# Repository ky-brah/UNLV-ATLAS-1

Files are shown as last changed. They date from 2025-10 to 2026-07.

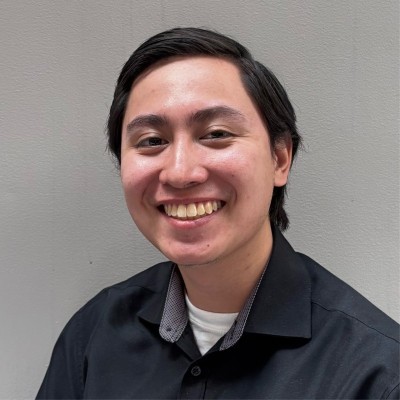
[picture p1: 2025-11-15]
img/Leo.jpg

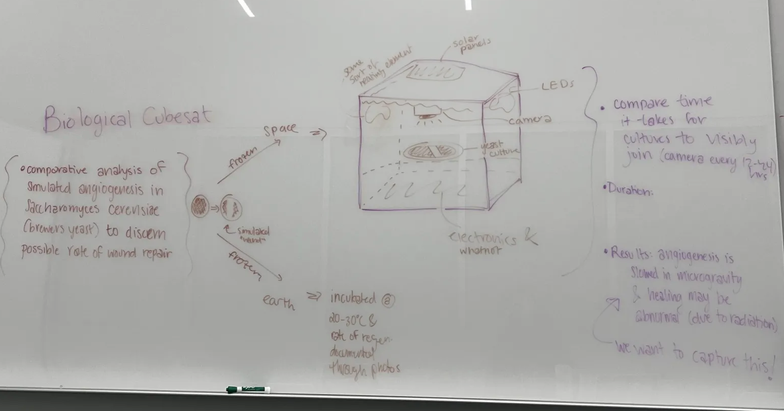
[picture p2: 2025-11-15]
img/biocubeidea.png

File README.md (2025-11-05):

# UNLV-ATLAS-1

UNLV ATLAS-1 is an independent research project at the University of Nevada, Las Vegas, dedicated to making high-altitude ballooning tests and CubeSat development more accessible and attainable within the Nevada region.

This GitHub repository documents our ongoing progress toward our mission: to design, build, and launch a CubeSat from the state of Nevada. Our goal is not only to showcase innovation but also to strengthen Nevada’s presence in the aerospace industry. We are currently developing ATLAS-1, an open-source mock satellite (“mocksat”) that enables high-altitude balloon launches on a budget. All source files and resources for this project can be found here.

We would like to acknowledge jhammerberg’s qbSat-v2, whose original mocksat design served as the foundation upon which ATLAS-1 was developed and improved.

We encourage others to explore our design—modify it, build upon it, and make it their own.

Through this project, we aim to inspire future engineers and establish Nevada as a recognized contributor to the global space community.

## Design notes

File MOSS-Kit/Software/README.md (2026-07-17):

# MOSS Kit

A hands-on kit for building, flying, and recovering a real telemetry payload — the hardware, the code, and the docs that tie them together. Built by students, for students, as part of UNLV's ATLAS-1 high-altitude balloon platform.

## What's here

The folders in this directory are already arranged in the exact structure each Raspberry Pi expects. Don't rearrange them — the scripts write files relative to their own location, and the ground station's nginx setup depends on this layout.

-  Flight Pi (payload). The main flight program, shared pipeline modules, LoRa radio driver, and preflight tests. A `runs/` folder gets created at runtime, one timestamped folder per launch.
- ground — Ground Pi. The receiver, the dashboard it serves, the shared modules, and optional test scripts for checking things work with no radio attached.
- `MOSS-docs.html` — Full setup documentation. Open it in any browser.

## Getting the files onto your Pis

Download the whole thing as a ZIP straight from GitHub rather than cloning or copying files one at a time:

You can either get the whole repository, or simply the software folder.

The ZIP preserves the folder structure exactly as it appears here, which is why this is the recommended way to get started.

## The most important rule

`tm_schema.py` and `protocol_tm.py` must be **byte-identical copies** on both Pis. They aren't shared over the network — each Pi keeps its own copy. If the two drift apart, the ground station can't decode anything the flight Pi sends.

Because the ZIP gives both Pis the same starting copies, downloading fresh is the simplest way to guarantee they match. To verify later:

```bash
sha256sum ~/hab/tm_schema.py ~/hab/protocol_tm.py       # flight Pi
sha256sum ~/ground/tm_schema.py ~/ground/protocol_tm.py # ground Pi
```
Note: The above file paths /hab may not be accurate to yours

If the fingerprints match, the files are the same.

## Step-by-step guide

**Open `MOSS-docs.html` in a browser** for the full walkthrough. It covers everything below in detail, with commands you can copy.

The recommended order:

1. **Main setup** — do this on both Pis. OS, connection, interfaces, Python. Four steps, once per Pi. Nothing else works until this is done.
2. **Ground station** — build and test this first. Install nginx, set the folder path, then prove the dashboard works using fake data. No radio needed, nothing to wire.
3. **Flight Pi** — the payload. Wire the sensors, confirm the bus sees each one, install the drivers, then run it. With the ground station already working, you can watch real telemetry arrive immediately.
4. **Field hotspot** — last of all. Only once both Pis work on ordinary Wi-Fi. This is purely for the launch site, where no network exists.

Ground before flight is deliberate: the ground station can be fully tested on a desk, so when you power up the payload, anything that goes wrong is on the flight side rather than a mystery split between the two.

## Hardware

| Component | Role |

| Raspberry Pi 3B+ | Flight computer |
| Sensor suite (BME280, LTR390, TSL2591, ICM20948) | Environmental + motion data |
| Raspberry Pi Camera v2 | Imaging |

## Notes

- Paths in the docs use `unlvcube1` as the username (`/home/unlvcube1/hab/`). Yours will read `/home/<your-username>/` with whatever name you chose in Raspberry Pi Imager.
- Folder names (`hab`, `ground`) are examples. The structure is what matters.
- Wi-Fi never reaches the balloon in flight. It's only for the ground: starting scripts before launch and pulling data after recovery.

Questions, bugs, or ideas? Reach us at *contact TBD*.

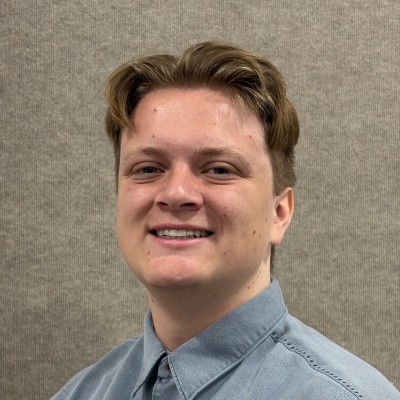
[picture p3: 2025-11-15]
img/Christian.jpg

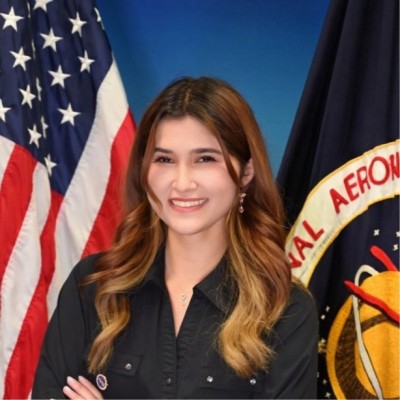
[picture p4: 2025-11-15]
img/Kylee.jpg

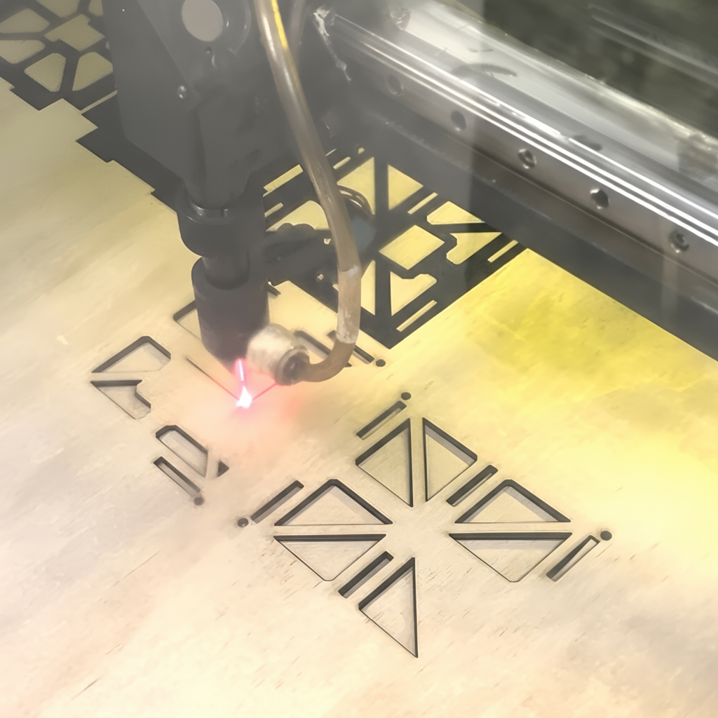
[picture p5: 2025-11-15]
img/Laser.jpg

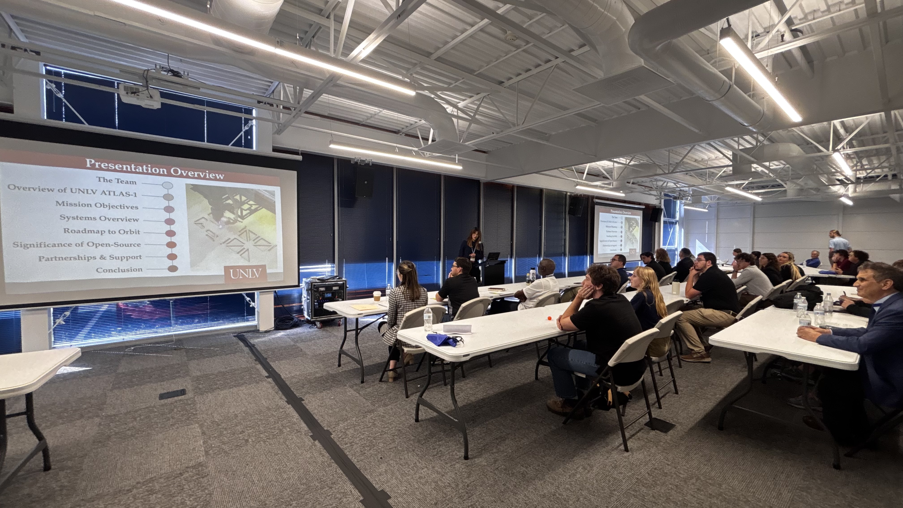
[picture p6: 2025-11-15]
img/present.jpeg

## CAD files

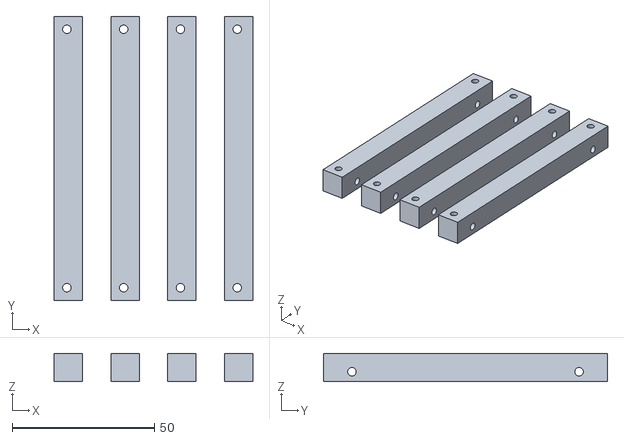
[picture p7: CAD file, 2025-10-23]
OutDated/ATLAS PILLAR V2.stl
70.0 x 100.0 x 10.0

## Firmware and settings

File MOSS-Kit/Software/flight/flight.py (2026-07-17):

#!/usr/bin/env python3
"""
flight.py
flight-side telemetry script.

Main idea
---------
- Build a telemetry record every 2 seconds (0.5 Hz).
- Log every record locally as JSONL (safety net — survives even if every
  radio packet is lost).
- Pack the record into a 22-byte binary payload via tm_schema.pack().
- Wrap that payload in a TM frame via protocol_tm.build_frame().
- Transmit the frame twice back-to-back (2x retransmit strategy).
- Run the camera in its own worker thread so subprocess capture never
  blocks the main telemetry loop.

"""

# =====================================================================
# STUDENT ORIENTATION — read this first
# ---------------------------------------------------------------------
# This program runs ON THE PAYLOAD (the Raspberry Pi that flies). Its job
# is a loop: read every sensor, write the full reading to the SD card,
# then send a compact copy to the ground over the radio. Repeat every 2s.
#
# Two rules the code follows everywhere:
#   1. NEVER let one broken part crash the flight. Every sensor/radio read
#      is wrapped so a failure is caught, recorded in the record's "errors",
#      and the loop keeps going. A dead sensor must not silence the others.
#   2. The SD card log (JSONL) is the source of truth. The radio is
#      best-effort — many packets are lost in flight — so the local log is
#      what you actually analyze afterward.
#
# The "(value, error)" return pattern you'll see everywhere is how rule #1
# works: a function hands back BOTH a result AND an error string (one is
# always None), so the caller can log the problem instead of crashing.
# =====================================================================

# -------------------------
# Standard libraries
# -------------------------
import json
import math
import queue
import shutil
import subprocess
import threading
import time
from datetime import datetime, timezone
from pathlib import Path
from typing import Any, Dict, Optional

# -------------------------
# Hardware / sensor libraries
# -------------------------
# These only exist on the Raspberry Pi. board/busio (Adafruit Blinka) expose
# the Pi's I2C pins; the rest are drivers, one per sensor chip on the I2C bus:
#   BME280  -> temperature, pressure, humidity
#   LTR390  -> UV + ambient light
#   TSL2591 -> lux / infrared / visible light
#   ICM20948 (IMU) -> acceleration + rotation (gyro)
import board
import busio
from adafruit_bme280 import basic as adafruit_bme280
import adafruit_ltr390
import adafruit_tsl2591
from adafruit_icm20x import ICM20948

# UPS power monitoring (Waveshare UPS HAT E)
from smbus2 import SMBus

# LoRa driver
import sx126x

# Shared telemetry protocol (MUST match ground exactly)
from protocol_tm import build_frame as tm_build_frame

# Binary wire-format schema (MUST match ground exactly)
import tm_schema


# ===========================================================
# Constants
# ===========================================================

# ---- Telemetry pacing ----
TELEMETRY_HZ = 0.5           # 1 packet every 2 seconds
LOOP_PERIOD_S = 1.0 / TELEMETRY_HZ

# ---- UPS (Waveshare UPS HAT E) ----
UPS_I2C_ADDR   = 0x2D
LOW_BATT_PCT   = 20
CRIT_BATT_PCT  = 10
LOW_BATT_V     = 3.55

# ---- BME280 ----
# BME280 lives on either 0x76 or 0x77; we try 0x76 first.
BME280_PRIMARY_ADDR   = 0x76
BME280_FALLBACK_ADDR  = 0x77

# ---- IMU (ICM20948) ----
# Inertial Measurement Unit: accelerometer + gyroscope, on I2C address 0x68.
IMU_I2C_ADDR = 0x68

# Sea-level pressure used as fallback altitude reference if we can't
# capture a launch-pad reading at startup (in hPa).
DEFAULT_REF_PRESSURE_HPA = 1013.25

# ---- Camera ----
IMAGE_PERIOD_S       = 25 # capture cadence
IMG_W, IMG_H         = 3280, 2464
IMG_Q                = 85
CAMERA_TIMEOUT_S     = 8
CRIT_IMAGE_PERIOD_S  = 60 # slow capture when battery critical

# ---- LoRa ----
LORA_PORT          = "/dev/serial0"
LORA_FREQ_MHZ      = 915
LORA_SRC_ADDR      = 1
LORA_DEST_ADDR     = 65535
LORA_POWER_DBM     = 22
LORA_AIR_SPEED     = 2400
LORA_NET_ID        = 0
LORA_CRYPT         = 0
LORA_RSSI          = True
LORA_BUFFER_SIZE   = 240
LORA_BASE_FREQ_MHZ = 850 # 900MHz modules: offset = freq_mhz - 850

# 2x retransmit — send each frame twice back-to-back for resilience.
TX_COPIES          = 2
TX_GAP_S           = 0.05  # tiny gap between copies so UART isn't slammed

# ---- Storage ----
MAX_LOG_MB   = 200
MAX_IMAGE_MB = 500


# ==================================================================
# Time helpers
# ===================================================================
def utc_timestamp_iso() -> str:
    return datetime.now(timezone.utc).isoformat(timespec="milliseconds")


def sleep_to_rate(loop_start_s: float, period_s: float) -> None:
    """Sleep just long enough to keep the main loop at the target rate."""
    elapsed = time.time() - loop_start_s
    time.sleep(max(0.0, period_s - elapsed))


# ==================================================================
# Local logging (JSONL)
# ===================================================================
def append_jsonl(path: Path, record: Dict[str, Any]) -> Optional[str]:
    # JSONL = one complete JSON object per line. Appending a line at a time
    # means a power loss only risks the last line, not the whole file.
    # Returns None on success or an error string (never raises — keep flying).
    try:
        with path.open("a", encoding="utf-8") as f:
            f.write(json.dumps(record, separators=(",", ":"), ensure_ascii=False) + "\n")
        return None
    except Exception as e:
        return repr(e)


# ====================================================================
# Storage cleanup (delete oldest files when folder over the cap)
# =====================================================================
def cleanup_folder_to_mb(folder: Path, max_mb: int) -> int:
    if not folder.exists():
        return 0

    max_bytes = max_mb * 1024 * 1024
    files = [p for p in folder.rglob("*") if p.is_file()]
    files.sort(key=lambda p: p.stat().st_mtime)

    total = sum(p.stat().st_size for p in files)
    if total <= max_bytes:
        return 0

    deleted = 0
    for p in files:
        try:
            size = p.stat().st_size
            p.unlink()
            total -= size
            deleted += 1
            if total <= max_bytes:
                break
        except Exception:
            pass
    return deleted


# ======================================================================
# UPS helpers
# ======================================================================
def ups_read_u16(bus: SMBus, reg: int) -> int:
    # The battery gauge stores values across two 8-bit registers. Read the low
    # byte and high byte, then stitch them into one unsigned 16-bit number.
    lo = bus.read_byte_data(UPS_I2C_ADDR, reg)
    hi = bus.read_byte_data(UPS_I2C_ADDR, reg + 1)
    return (hi << 8) | lo


def ups_read_i16(bus: SMBus, reg: int) -> int:
    # Same as above but SIGNED: current is negative when discharging, so a
    # value with the top bit set is converted to its negative (two's-complement).
    v = ups_read_u16(bus, reg)
    return v - 65536 if v & 0x8000 else v


def read_ups_status(bus: SMBus) -> tuple[Dict[str, Any], Optional[str]]:
    try:
        batt_mv  = ups_read_u16(bus, 0x20)
        batt_ma  = ups_read_i16(bus, 0x22)
        batt_pct = ups_read_u16(bus, 0x24)
        rem_mah  = ups_read_u16(bus, 0x26)
        rem_min  = ups_read_u16(bus, 0x28)
        return {
            "battery_v": batt_mv / 1000.0,
            "battery_a": batt_ma / 1000.0,
            "battery_pct": batt_pct,
            "remaining_mah": rem_mah,
            "remaining_min": rem_min,
        }, None
    except Exception as e:
        return {}, repr(e)


def compute_battery_alerts(power: Dict[str, Any]) -> list[str]:
    alerts: list[str] = []
    pct = power.get("battery_pct")
    v   = power.get("battery_v")

    if isinstance(pct, (int, float)):
        if pct <= CRIT_BATT_PCT:
            alerts.append("BATT_CRIT_PCT")
        elif pct <= LOW_BATT_PCT:
            alerts.append("BATT_LOW_PCT")

    if isinstance(v, (int, float)) and v <= LOW_BATT_V:
        alerts.append("BATT_LOW_V")

    return alerts


# =======================================================================
# Pi health helpers (kept for JSONL log; not in radio packet)
# ========================================================================
def _run(cmd: list[str]) -> tuple[str, Optional[str]]:
    try:
        out = subprocess.check_output(cmd, stderr=subprocess.STDOUT, text=True)
        return out.strip(), None
    except Exception as e:
        return "", repr(e)


def read_cpu_temp_c() -> tuple[Optional[float], Optional[str]]:
    out, err = _run(["vcgencmd", "measure_temp"])
    if err:
        return None, err
    try:
        return float(out.split("=")[1].split("'")[0]), None
    except Exception as e:
        return None, repr(e)


def read_disk_free_mb(path: Path) -> tuple[Optional[float], Optional[str]]:
    try:
        return shutil.disk_usage(str(path)).free / (1024 * 1024), None
    except Exception as e:
        return None, repr(e)


def read_pi_health(data_root: Path) -> tuple[Dict[str, Any], Dict[str, str]]:
    health: Dict[str, Any] = {}
    errors: Dict[str, str] = {}

    cpu_temp, err = read_cpu_temp_c()
    if err:
        errors["cpu_temp"] = err
    else:
        health["cpu_temp_c"] = cpu_temp

    disk_free, err = read_disk_free_mb(data_root)
    if err:
        errors["disk_free"] = err
    else:
        health["disk_free_mb"] = disk_free

    return health, errors


# ======================================================================
# Sensors (BME280 + LTR390 + TSL2591 + ICM20948)
# =======================================================================
def init_i2c_bus() -> busio.I2C:
    return busio.I2C(board.SCL, board.SDA)


def init_sensors(i2c: busio.I2C) -> Dict[str, Any]:
    """
    Initialize all I2C sensors. Each init is independent: one sensor failing
    does not stop the others. Init failures are recorded in
    sensors["_init_errors"] so downstream telemetry can surface the real
    reason a field shows up null.

    BME280 address is commonly 0x76 or 0x77. We try 0x76 first, then 0x77.
    """
    # Each sensor gets its own slot, defaulting to None. If a sensor fails to
    # initialize, its slot stays None and the rest still work — later reads
    # check "is this None?" before using it. Init errors collect in one dict.
    sensors: Dict[str, Any] = {
        "bme280_sensor": None,
        "ltr390_sensor": None,
        "tsl2591_sensor": None,
        "imu_sensor": None,
        "_init_errors": {},
    }
    init_errors: Dict[str, str] = {}

    # Each try/except below is independent on purpose: a missing or broken
    # sensor records its error and the next sensor still gets initialized.

    # --- BME280 (temp/pressure/humidity) ---
    # Try address 0x76 first, fall back to 0x77 (depends on the breakout).
    try:
        sensors["bme280_sensor"] = adafruit_bme280.Adafruit_BME280_I2C(
            i2c, address=BME280_PRIMARY_ADDR
        )
    except Exception as e76:
        try:
            sensors["bme280_sensor"] = adafruit_bme280.Adafruit_BME280_I2C(
                i2c, address=BME280_FALLBACK_ADDR
            )
        except Exception as e77:
            init_errors["bme280_init"] = (
                f"0x76 failed: {type(e76).__name__}: {e76}; "
                f"0x77 failed: {type(e77).__name__}: {e77}"
            )

    # --- LTR390 (UV / ambient light) ---
    try:
        sensors["ltr390_sensor"] = adafruit_ltr390.LTR390(i2c)
    except Exception as e:
        init_errors["ltr390_init"] = f"{type(e).__name__}: {e}"

    # --- TSL2591 (lux / IR / visible) ---
    try:
        sensors["tsl2591_sensor"] = adafruit_tsl2591.TSL2591(i2c)
    except Exception as e:
        init_errors["tsl2591_init"] = f"{type(e).__name__}: {e}"

    # --- IMU (ICM20948: accel + gyro) ---
    try:
        sensors["imu_sensor"] = ICM20948(i2c, address=IMU_I2C_ADDR)
    except Exception as e:
        init_errors["imu_init"] = f"{type(e).__name__}: {e}"

    sensors["_init_errors"] = init_errors
    return sensors


def read_bme280(sensor: Any) -> tuple[Dict[str, Any], Optional[str]]:
    """
    Read temperature, pressure, and humidity from the BME280.
    Altitude is computed later from pressure. Kept as its own function so
    the main loop can derive altitude from the pressure reading.
    """
    # The BME280 (with an "E") reads all three of these. Altitude is a DERIVED
    # value computed in the main loop, where the launch-pad reference pressure
    # is available — that's why it isn't returned here.
    try:
        return {
            "temperature_c": float(sensor.temperature),
            "pressure_hpa": float(sensor.pressure),
            "humidity_pct": float(sensor.humidity),
        }, None
    except Exception as e:
        return {}, repr(e)


def read_extra_sensors(sensors: Dict[str, Any]) -> tuple[Dict[str, Any], Dict[str, str]]:
    """
    Read the non-BME280 sensors (UV/ambient, lux/IR/visible, IMU).
    Returns (data, errors) where data is keyed by record section
    ("uv_light", "light", "imu"). BME280 is handled separately by
    read_bme280() because the main loop needs its pressure for altitude.
    """
    data: Dict[str, Any] = {}
    errors: Dict[str, str] = {}

    # Pull each sensor object; any that failed to init is None and is skipped.
    ltr390 = sensors.get("ltr390_sensor")
    tsl2591 = sensors.get("tsl2591_sensor")
    imu = sensors.get("imu_sensor")

    # UV + ambient light. Each block is guarded so one bad sensor doesn't
    # block the others (same "keep flying" rule as everywhere else).
    if ltr390 is not None:
        try:
            data["uv_light"] = {
                "uv_raw": float(ltr390.uvs),
                "ambient_light_raw": float(ltr390.light),
            }
        except Exception as e:
            errors["ltr390"] = repr(e)

    if tsl2591 is not None:
        try:
            data["light"] = {
                "lux": float(tsl2591.lux),
                "infrared": float(tsl2591.infrared),
                "visible": float(tsl2591.visible),
            }
        except Exception as e:
            errors["tsl2591"] = repr(e)

    # IMU: acceleration (m/s²) and rotation (rad/s), each as an (x, y, z) tuple.
    if imu is not None:
        try:
            accel_x, accel_y, accel_z = imu.acceleration
            gyro_x, gyro_y, gyro_z = imu.gyro
            data["imu"] = {
                "accel_mps2": [float(accel_x), float(accel_y), float(accel_z)],
                "gyro_rps": [float(gyro_x), float(gyro_y), float(gyro_z)],
            }
        except Exception as e:
            errors["icm20948"] = repr(e)

    return data, errors


def pressure_to_altitude(p_hpa: float, ref_p_hpa: float) -> float:
    """
    International barometric formula.

    Altitude (m) above the reference-pressure level. Use the launch-pad
    pressure as the reference so the returned value is altitude above
    launch site, not above mean sea level.
    """
    # Air pressure falls in a known way as you climb; this inverts that to
    # get height. The constants come from the standard atmosphere model.
    return 44330.0 * (1.0 - math.pow(p_hpa / ref_p_hpa, 0.1903))


def capture_reference_pressure(sensor: Any, samples: int = 10) -> tuple[float, Optional[str]]:
    """
    Average a few BMP280 readings at startup to use as the launch-pad
    reference. Returns the default 1013.25 hPa if reads fail.
    """
    # (The sensor is a BME280; "BMP280" in the line above is just a label
    # holdover.) Averaging several samples smooths out noise so "ground = 0 m"
    # is a stable baseline. If it can't read, fall back to standard sea-level
    # pressure — altitude then reads vs. sea level rather than the pad.
    if sensor is None:
        return DEFAULT_REF_PRESSURE_HPA, "no_sensor"

    readings = []
    for _ in range(samples):
        try:
            readings.append(float(sensor.pressure))
            time.sleep(0.1)
        except Exception:
            pass

    if not readings:
        return DEFAULT_REF_PRESSURE_HPA, "no_readings"

    return sum(readings) / len(readings), None


# ===================================================================
# Camera worker (subprocess in a background thread)
# ===================================================================
class CameraWorker:
    """
    Runs rpicam-still in a background thread so the main loop never blocks.

    Usage
    -----
    worker = CameraWorker(images_dir)
    worker.start()
    ...
    worker.request_capture(seq)         # non-blocking; main loop keeps going
    status = worker.snapshot_status()   # safe to read every loop
    ...
    worker.stop()
    """
    # WHY A THREAD: taking a photo takes a few seconds. Doing it in the main
    # loop would freeze telemetry during every capture, so the camera runs on
    # its own thread — the main loop just drops a request in a queue and moves on.

    def __init__(self, images_dir: Path) -> None:
        self.images_dir = images_dir
        # Mailbox of capture requests. maxsize=4: if the camera falls behind,
        # new requests are dropped rather than piling up without bound.
        self._queue: queue.Queue[int] = queue.Queue(maxsize=4)
        self._thread: Optional[threading.Thread] = None
        self._stop_evt = threading.Event()   # thread-safe "please stop" flag
        self._lock = threading.Lock()         # guards the shared status dict

        # Status updated by the worker, read by the main loop.
        self._last_status: Dict[str, Any] = {
            "captured": False,
            "seq": None,
            "path": None,
            "bytes": None,
            "error": None,
        }

    def start(self) -> None:
        self._thread = threading.Thread(target=self._run, name="CameraWorker", daemon=True)
        self._thread.start()

    def stop(self) -> None:
        self._stop_evt.set()
        if self._thread is not None:
            self._thread.join(timeout=2.0)

    def request_capture(self, seq: int) -> bool:
        """Returns False if the queue is full (capture skipped)."""
        try:
            self._queue.put_nowait(seq)
            return True
        except queue.Full:
            return False

    def snapshot_status(self) -> Dict[str, Any]:
        """Return a copy of the latest capture status (thread-safe)."""
        with self._lock:
            return dict(self._last_status)

    def _set_status(self, status: Dict[str, Any]) -> None:
        with self._lock:
            self._last_status = status

    def _run(self) -> None:
        while not self._stop_evt.is_set():
            try:
                seq = self._queue.get(timeout=0.5)
            except queue.Empty:
                continue

            status = self._do_capture(seq)
            self._set_status(status)

    def _do_capture(self, seq: int) -> Dict[str, Any]:
        status: Dict[str, Any] = {
            "captured": False,
            "seq": seq,
            "path": None,
            "bytes": None,
            "error": None,
        }
        try:
            self.images_dir.mkdir(parents=True, exist_ok=True)
            img_path = self.images_dir / f"img_{seq:06d}.jpg"

            cmd = [
                "rpicam-still",
                "-n",
                "-t", "300",
                "--width", str(IMG_W),
                "--height", str(IMG_H),
                "-q", str(IMG_Q),
                "-o", str(img_path),
            ]

            # timeout kills a hung capture (the exact bug that lost all of
            # ATLAS-1's photos); check=True raises on a non-zero exit. Either
            # way it's caught below and logged, never crashing the flight.
            subprocess.run(
                cmd,
                check=True,
                stdout=subprocess.DEVNULL,
                stderr=subprocess.DEVNULL,
                timeout=CAMERA_TIMEOUT_S,
            )

            status["path"] = str(img_path)
            status["bytes"] = int(img_path.stat().st_size)
            status["captured"] = True
        except Exception as e:
            status["error"] = repr(e)

        return status


# =====================================================================
# LoRa
# =====================================================================
def init_lora() -> tuple[Optional[Any], Optional[str]]:
    #validating frequency offset before touching radio
    try:
        freq_off = compute_freq_off(LORA_FREQ_MHZ)
    except ValueError as e:
        return None, f"freq_offsetOinvalid: {e}"
    try:
        lora = sx126x.sx126x(
            serial_num=LORA_PORT,
            freq=LORA_FREQ_MHZ,
            addr=LORA_SRC_ADDR,
            power=LORA_POWER_DBM,
            rssi=LORA_RSSI,
            air_speed=LORA_AIR_SPEED,
            net_id=LORA_NET_ID,
            buffer_size=LORA_BUFFER_SIZE,
            crypt=LORA_CRYPT,
            relay=False,
            lbt=False,
            wor=False,
        )
        return lora, None
    except Exception as e:
        return None, repr(e)


def compute_freq_off(freq_mhz: int) -> int:
    off = int(freq_mhz) - int(LORA_BASE_FREQ_MHZ)
    if not (0 <= off <= 255):
        raise ValueError(
            f"Frequency offset out of range: freq={freq_mhz} base={LORA_BASE_FREQ_MHZ} off={off}"
        )
    return off


def build_addressed_frame(dest_addr: int, payload: bytes) -> bytes:
    """Prepend the SX126x fixed-address header [DEST_H][DEST_L][FREQ_OFF]."""
    freq_off = compute_freq_off(LORA_FREQ_MHZ)
    return bytes([
        (dest_addr >> 8) & 0xFF,
        dest_addr & 0xFF,
        freq_off & 0xFF,
    ]) + payload
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

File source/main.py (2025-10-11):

from flask_socketio import SocketIO, emit
from flask import Flask, render_template
from picamera2.encoders import MJPEGEncoder
from picamera2.outputs import FileOutput
from picamera2 import Picamera2
#from enviroplus import gas
import threading
import datetime
import base64
import time
import csv
import io
import os

from sense_hat import SenseHat


#Import Sensors
#from bme280 import BME280 # Temperature / Pressure / Humidity Sensor
#from ltr559 import LTR559 # Lights / Proximity

#Setup Sensor Variables
#bme280 = BME280()
#ltr559 = LTR559()

global toggle, writing, currentConnections, readings
currentConnections = 0
toggle = False
writing = False
startTime = time.time()

sense = SenseHat()


app = Flask(__name__, template_folder="Gemini/templates", static_folder="Gemini/static") 
socket = SocketIO(app, logger=False, engineio_logger=False) 
camera = Picamera2() 
config = camera.create_video_configuration(
    buffer_count=10, #Increasing frame buffer decreases dropped frames but increases latency
    main={"size": (640, 480)},
    #controls={"FrameDurationLimits": (10_000, 10_000)} #10 FPS
    controls={"FrameDurationLimits": (10_000, 33_000)} #29 FPS
    #controls={"FrameDurationLimits": (33_333, 33_333)} #30 FPS
    )
camera.configure(config)

### Meta Functions
    
def millis(): #debugging function remove on final build
    return round((time.time()-startTime)*1000)

def setFrame(data: bytes) -> None: 
    global frame
    frame = data

def jpgToB64(data):
    img64 = "data:image/jpg;base64, " + str(base64.b64encode(data).decode("ascii")) #Converts image to base64, reformates and adds meta data.
    return(img64) #This isn't perfect but I couldn't find a different way to send frames over websockets so whatever

### Main Functions

def sensorData():
    global readings
    while True:
        try: #Sometimes the i2c bus fails and this stops that from crashing the server
            gyro = sense.get_gyroscope_raw()
            gyro_txt =f"X: {gyro['x']:.2f}, Y: {gyro['y']:.2f}, Z: {gyro['z']:.2f}"
            accel = sense.get_accelerometer_raw()
            accel_txt =f"X: {accel['x']:.2f}, Y: {accel['y']:.2f}, Z: {accel['z']:.2f}"
            mag = sense.get_compass_raw()
            mag_txt =f"X: {mag['x']:.2f}, Y: {mag['y']:.2f}, Z: {mag['z']:.2f}"
            readings = [
                str(round(sense.get_temperature(), 2))+" C",
                str(round(sense.get_pressure(), 2))+" hPa",
                str(round(sense.get_humidity(), 2))+" %",
                gyro_txt,
                accel_txt,
                mag_txt]
        except:
            print("error reading sensors, trying again.")
sensors = threading.Thread(target=sensorData) #This runs in the background because the time it takes to read sensors is enough to through off frame timing

def sendVideo(): #Sends frames to the client
    global frame, readings, currentConnections
    readings = None #If the sensors haven't read yet, this will prevent a crash
    lastFrame = None
    lastReadings = None
    while currentConnections >= 1: 
        if (frame != lastFrame):
            lastFrame = frame
            socket.emit("frame", jpgToB64(frame))
            socket.sleep(0) #Needed to stop the code from blocking
        if (readings != lastReadings):
            lastReadings = readings
            socket.emit("sensorData", readings)
            socket.sleep(0)

def cameraStart(): #Starts the camera and overwrites the stream write function to save the current frame as a variable
    global stream
    byteStream = io.BytesIO()
    byteStream.write = setFrame #Sets byteStream.write to call setFrame instead
    camera.start_recording(MJPEGEncoder(bitrate=5_000_000), FileOutput(byteStream)) #Modify bitrate to tweak performance
    print("Camera started.")

def recordLoop():
    global writing, frame, readings
    lastFrame = None
    lastReadings = None
    socket.emit("recordingIndicatorOn")
    sensor_data_file = csv.writer(open("Gemini/Sensor_Data.csv", "w"), delimiter=",", quotechar='"', quoting=csv.QUOTE_MINIMAL)
    with open("Gemini/current_recording.mjpeg", "wb") as video_file:
        sensor_data_file.writerow(["Time", "Humidity", "Pressure", "Temperature", "Light", "Oxidization", "Reduced Oxygen", "Ammonia"])
        while toggle == True:
            if (frame != lastFrame):
                lastFrame = frame
                writing = True
                video_file.write(frame) 
                writing = False
            if (readings != lastReadings):
                lastReadings = readings
                writing = True
                sensor_data_file.writerow([datetime.datetime.now().strftime("%d-%m-%Y_%I-%M-%S"), readings[0], readings[1], readings[2], readings[3], readings[4], readings[5], readings[6]])
                writing = False
    print("re-encoding recording") 
    socket.emit("recordingIndicatorOff")
    socket.emit("encodingIndicatorOn")
    #Starts an ffmpeg process to re-encode the recording to a mp4 file in the background and then deletes the file when it's done
    os.system("ffmpeg -loglevel quiet -i Gemini/current_recording.mjpeg -c:v libx264 -c:a copy Gemini/static/recording/current_recording.mp4 -y && rm Gemini/current_recording.mjpeg &")
recording = threading.Thread(target=recordLoop) #Creates a thread to record video to avoid blocking

### Websocket Functions

@socket.on("recordToggle")
def recordToggle():
    global toggle
    if toggle == False:
        toggle = True
        print("now recording")
        recording.start()
    else:
        toggle = False
        print("stopped recording")
        recording.join()
        while True:
            if os.path.isfile("Gemini/current_recording.mjpeg") == False:
                print("re-encoding complete, zipping file")
                os.system("zip -j Gemini/static/recording/" + datetime.datetime.now().strftime("%d-%m-%Y_%I:%M:%S") + ".zip Gemini/static/recording/current_recording.mp4 Gemini/Sensor_Data.csv && rm Gemini/Sensor_Data.csv && rm Gemini/static/recording/current_recording.mp4 &")
                if os.path.isfile("Gemini/current_recording.mp4") == False:
                    print("zip complete")
                    socket.emit("encodingIndicatorOff")
                    break
            else:
                socket.sleep(0)

@socket.on("connect") 
def connection():
    socket.emit("confirmConnect")
    print("New WebSocket Connection")
    if toggle == True:
        socket.emit("recordingIndicatorOn")
    else:
        socket.emit("recordingIndicatorOff")
    global currentConnections
    currentConnections += 1 

@socket.on("disconnect")
def disconnect():
    print("WebSocket Connection Closed")
    global currentConnections
    currentConnections -= 1
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

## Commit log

2025-10-23 Delete ATLAS PILLAR V1.stl
    Issue with Hole Alignment.
    [ATLAS PILLAR V1.stl]
2025-10-23 Add files via upload
    Fixed hole alignment...probably.
    [ATLAS PILLAR V2.stl]
2025-11-05 Delete Assembly.V1.zip
    Issues with Assembly Strength. Fixed in V2.
2026-07-17 Add commented ground scripts
2026-07-17 MOSSKIT current html file
2026-07-24 Moved unused files to outdated.
    [ATLAS PILLAR V2.stl]
2026-07-24 Attempting to fix duplicate files.
    [ATLAS PILLAR V2.stl]
